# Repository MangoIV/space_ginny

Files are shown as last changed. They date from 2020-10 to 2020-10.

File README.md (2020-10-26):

# space_ginny
## What is this?
This is basically a ginny clone. Ginny is a hackable asetniop input device by Germ distributed on gboards.ca with closed source hardware and open source software.

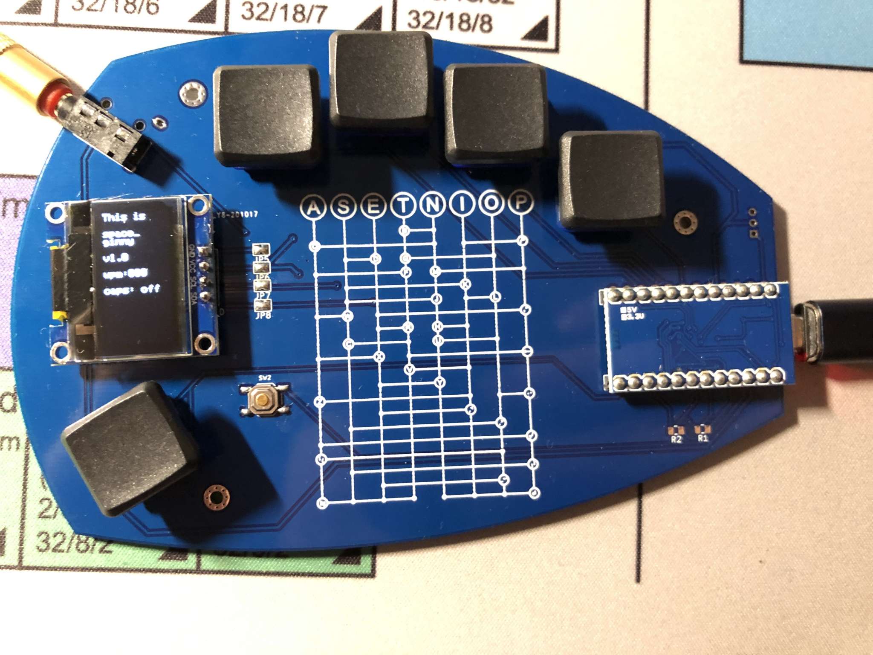
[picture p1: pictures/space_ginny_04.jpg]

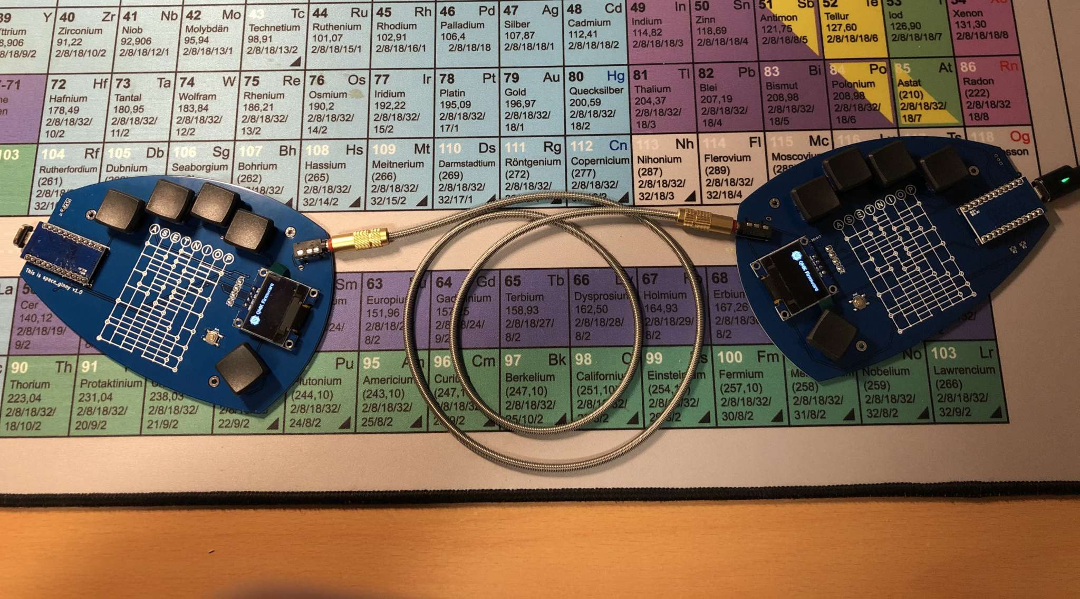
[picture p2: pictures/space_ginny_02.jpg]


## Who is this for?
This is for all the people who can't afford shipping from canada or want an OLED or a custom pcb colour on their ginny. 
This is also for all the people who like a more aggressive row stagger.
Furthermore it is for all the people who don't want to solder more than they need to. 

## What is the current state of the project?
The first PCBs have been ordered and are soldered and running QMK. Although there is no complete firmware yet, it is therefore proven that the hardware is able to be run as asetniop input device.
The next step is to create a working asetniop firmware. 

## What do you need to build a space_ginny?
The PCBs are reversible. You will need two of those. You will also need 2 pro micros or equivalents like the elite-c. Additionally you'll need 2 trrs jacks and 10 mx/choc switches and caps. 
2 reset buttons are not necessary but it will be more convenient for you to reset the board. The OLEDs aren't necessary either and you of course can leave them out if you want to go wireless or don't like them.

## How would you build them
Put headers in the outlined rectangles on the pro micro footprints. Solder them. Solder switches on same side. Solder TRRS jacks. Solder OLEDs. Bridge the jumpers on the top side. Solder the reset switch on the top side. Solder the switches. 
Repeat this whole procedure for the other pcb, this time on the backside.

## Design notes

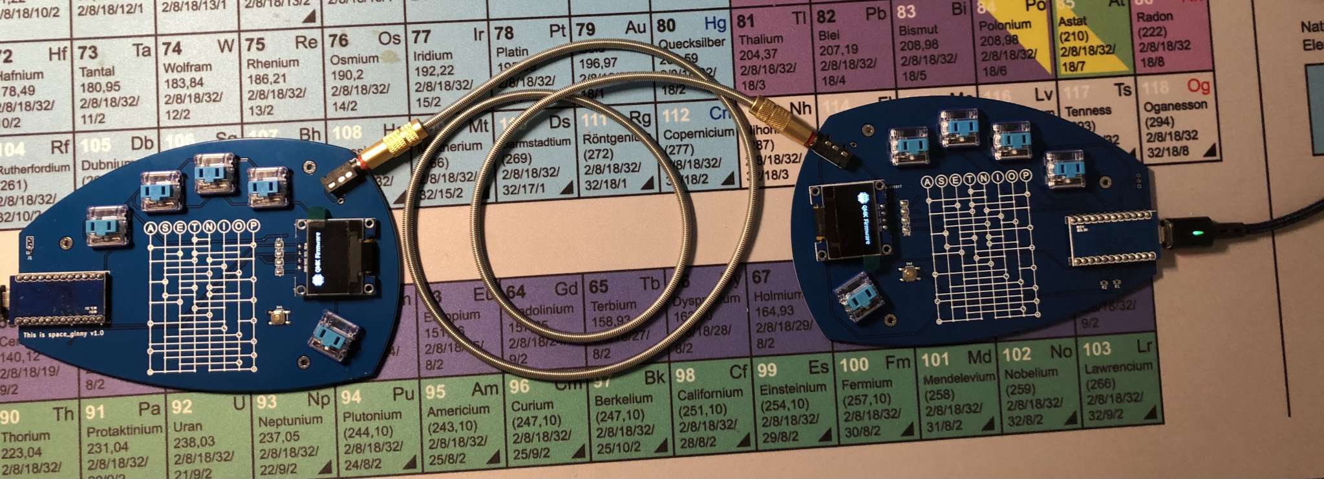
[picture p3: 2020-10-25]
pictures/space_ginny_03.jpg

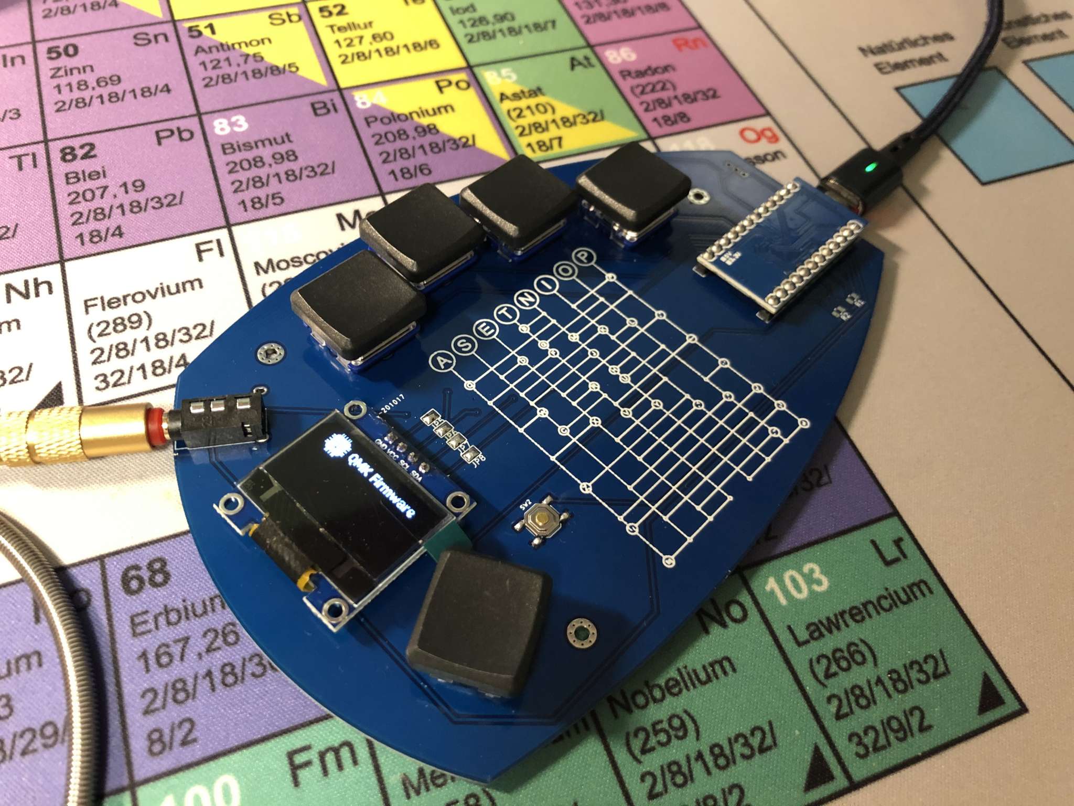
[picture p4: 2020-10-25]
pictures/space_ginny_01.jpg

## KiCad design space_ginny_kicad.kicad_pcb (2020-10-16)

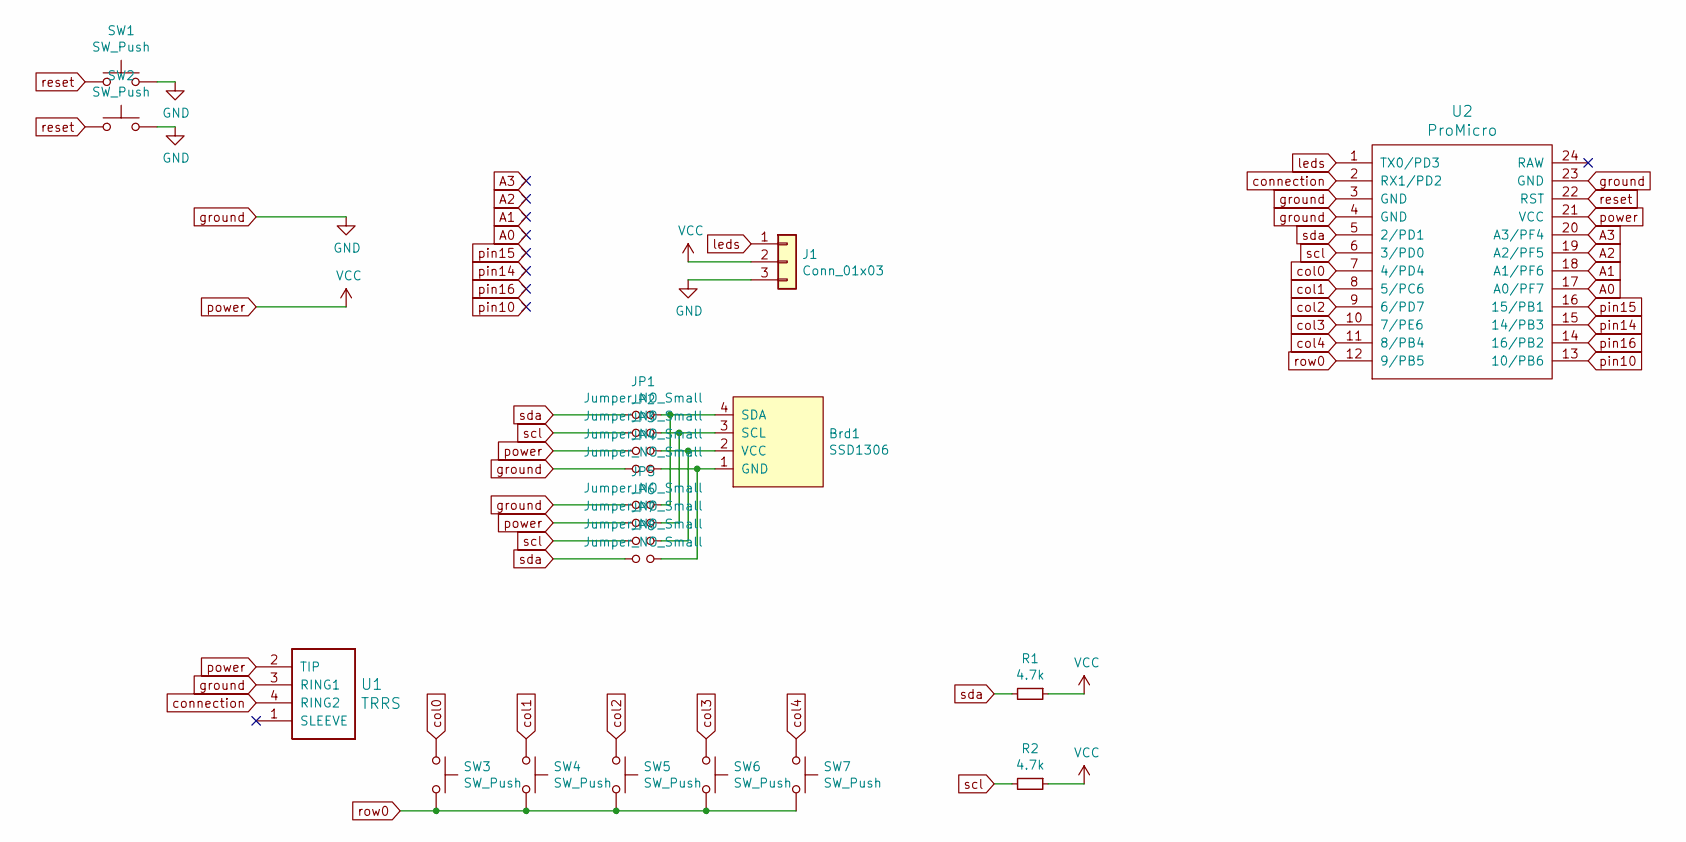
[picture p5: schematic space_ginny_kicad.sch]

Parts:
Brd1: SSD1306; 128x64OLED
J1: Conn_01x03; PinSocket_1x03_P2.00mm_Vertical
JP1, JP2, JP3, JP4, JP5, JP6, JP7, JP8: Jumper_NO_Small; SolderJumper-2_P1.3mm_Open_Pad1.0x1.5mm
R1, R2: 4.7k; R_0805_2012Metric
SW1, SW2: SW_Push; SW_SPST_TL3342
SW3, SW4, SW5, SW6, SW7: SW_Push; CherryMX_Choc_1u_reversible
U1: TRRS; TRRS-PJ-320A-dual
U2: ProMicro

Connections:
A0: U2.17 (A0/PF7)
A1: U2.18 (A1/PF6)
A2: U2.19 (A2/PF5)
A3: U2.20 (A3/PF4)
unnamed: Brd1.1 (GND), JP4.2, JP8.2
unnamed: Brd1.2 (VCC), JP3.2, JP7.2
unnamed: Brd1.3 (SCL), JP2.2, JP6.2
unnamed: Brd1.4 (SDA), JP1.2, JP5.2
col0: SW3.1, U2.7 (4/PD4)
col1: SW4.1, U2.8 (5/PC6)
col2: SW5.1, U2.9 (6/PD7)
col3: SW6.1, U2.10 (7/PE6)
col4: SW7.1, U2.11 (8/PB4)
connection: U1.4 (RING2), U2.2 (RX1/PD2)
ground: J1.3, JP4.1, JP5.1, SW1.2, SW2.2, U1.3 (RING1), U2.3 (GND), U2.4 (GND), U2.23 (GND)
leds: J1.1, U2.1 (TX0/PD3)
pin10: U2.13 (10/PB6)
pin14: U2.15 (14/PB3)
pin15: U2.16 (15/PB1)
pin16: U2.14 (16/PB2)
power: J1.2, JP3.1, JP6.1, R1.1, R2.1, U1.2 (TIP), U2.21 (VCC)
reset: SW1.1, SW2.1, U2.22 (RST)
row0: SW3.2, SW4.2, SW5.2, SW6.2, SW7.2, U2.12 (9/PB5)
scl: JP2.1, JP7.1, R2.2, U2.6 (3/PD0)
sda: JP1.1, JP8.1, R1.2, U2.5 (2/PD1)

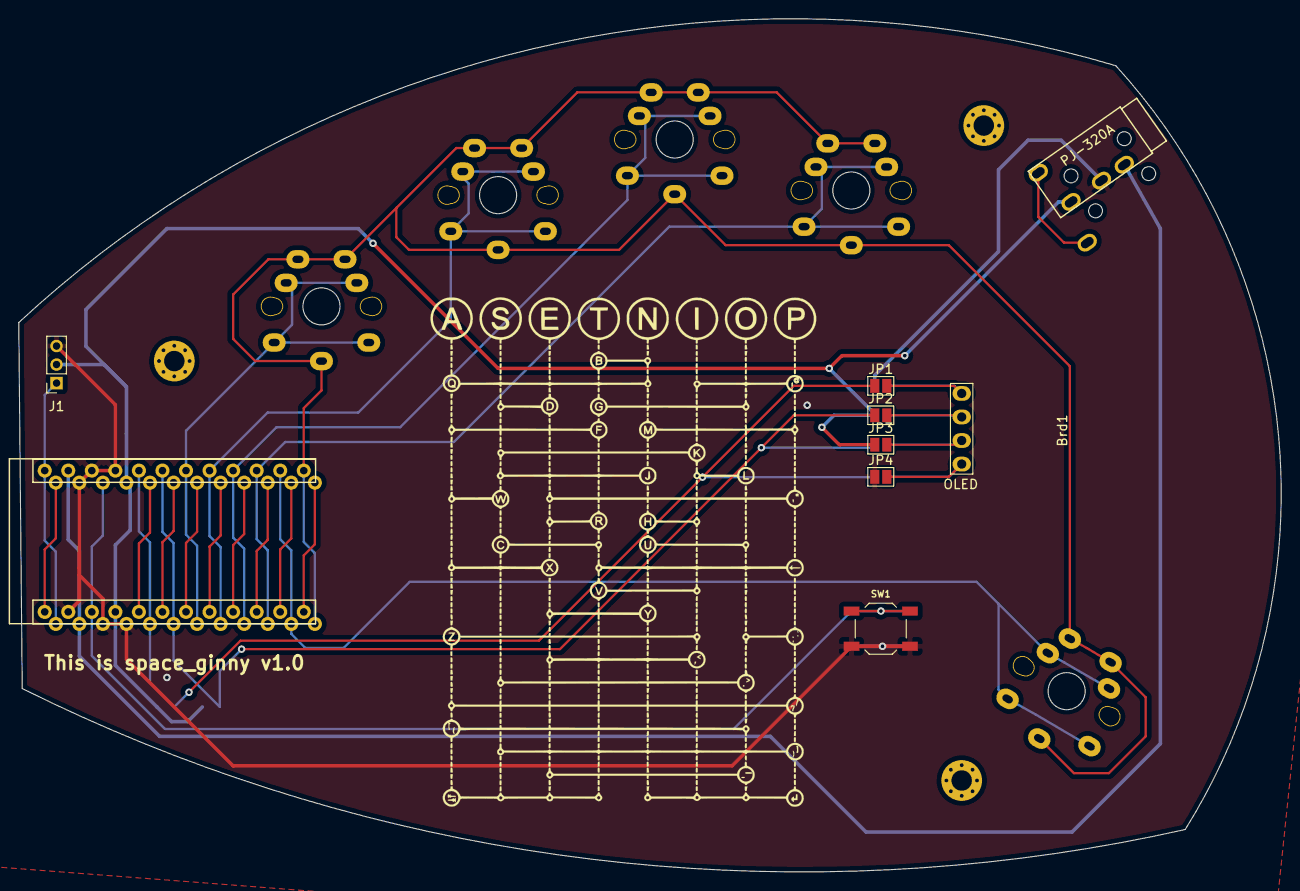
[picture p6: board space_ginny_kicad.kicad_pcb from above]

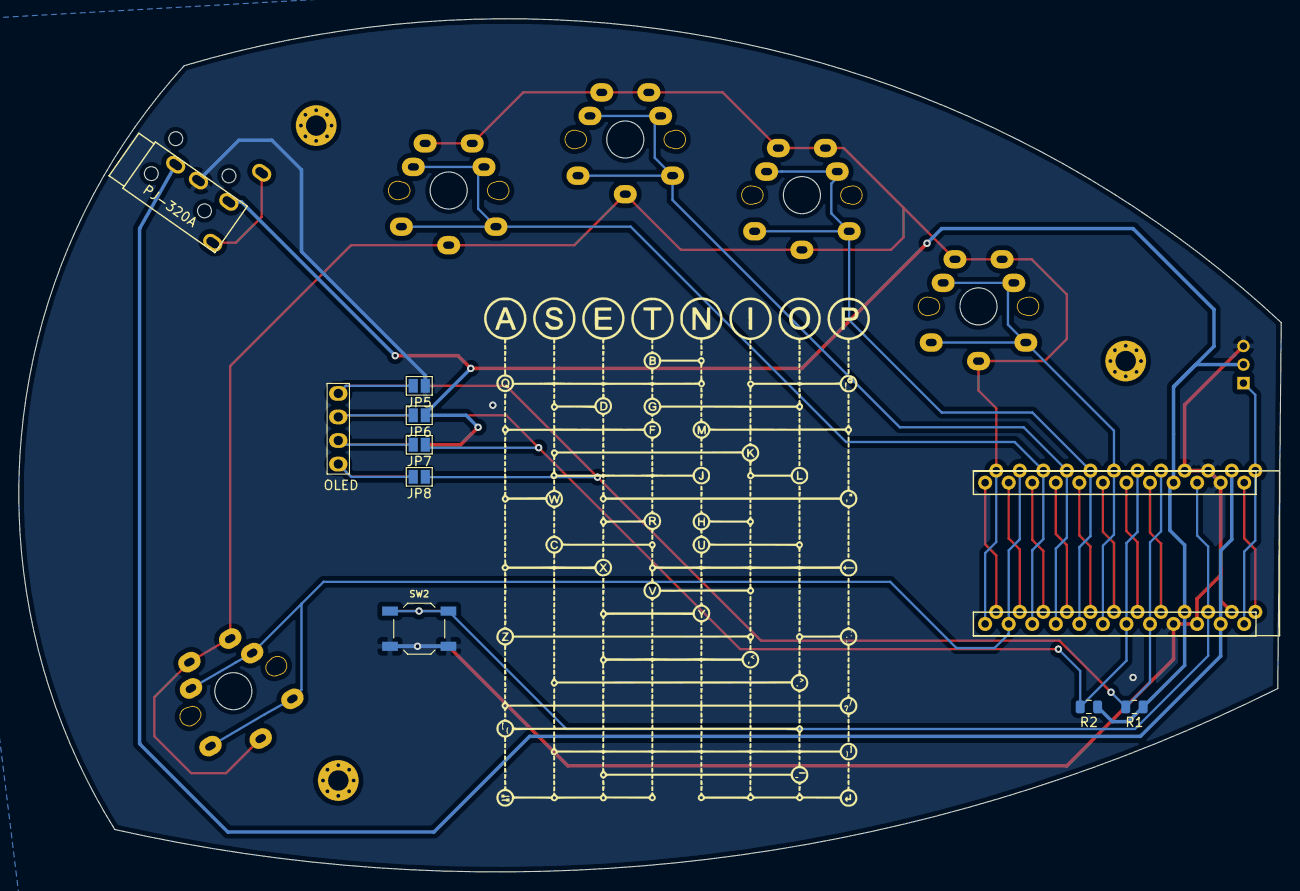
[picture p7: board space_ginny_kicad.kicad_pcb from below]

Board: 2 copper layers, 136.2 x 92.0 mm, 24 parts (8 on the bottom side), 17 nets.

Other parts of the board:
 : MountingHole_2.2mm_M2_Pad_Via
 #2,  #3: MountingHole_2.2mm_M2_Pad_Via

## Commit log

2020-10-14 added git submodules and initialised project
    [prominny_kicad.kicad_pcb, prominny_kicad.sch]
2020-10-14 added some footprints to the schematic
2020-10-14 added footpring for ssd 1306 as well as the corresponding symbol
    [prominny_kicad.sch]
2020-10-14 finished the schematics, so far
    [prominny_kicad.sch]
2020-10-14 - started the PCB design - finished the schematics (a second time ) - changed the LEDs to ws2812b (per key doesn't make sense with 5 keys)
    [prominny_kicad.kicad_pcb, prominny_kicad.sch]
2020-10-15 arranges, added edgecuts, started routing
    [prominny_kicad.kicad_pcb, prominny_kicad.sch]
2020-10-15 removed the LEDs cause they're useless ans instead added a breakout to add a strip if needed. Finished routing
    [prominny_kicad.kicad_pcb, prominny_kicad.sch]
2020-10-15 added groundfill and exported the outlines in svgs (new folder)
    [prominny_kicad.kicad_pcb]
2020-10-15 added silkscreen art, placed some traces new
    [prominny_kicad.kicad_pcb]
2020-10-16 changed mounting holes, added backside graphic
    [prominny_kicad.kicad_pcb]
2020-10-16 changed filenames, generated gerbers and drill files
    [prominny_kicad-B_Cu.gbr, prominny_kicad-B_Mask.gbr, prominny_kicad-B_Paste.gbr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]
